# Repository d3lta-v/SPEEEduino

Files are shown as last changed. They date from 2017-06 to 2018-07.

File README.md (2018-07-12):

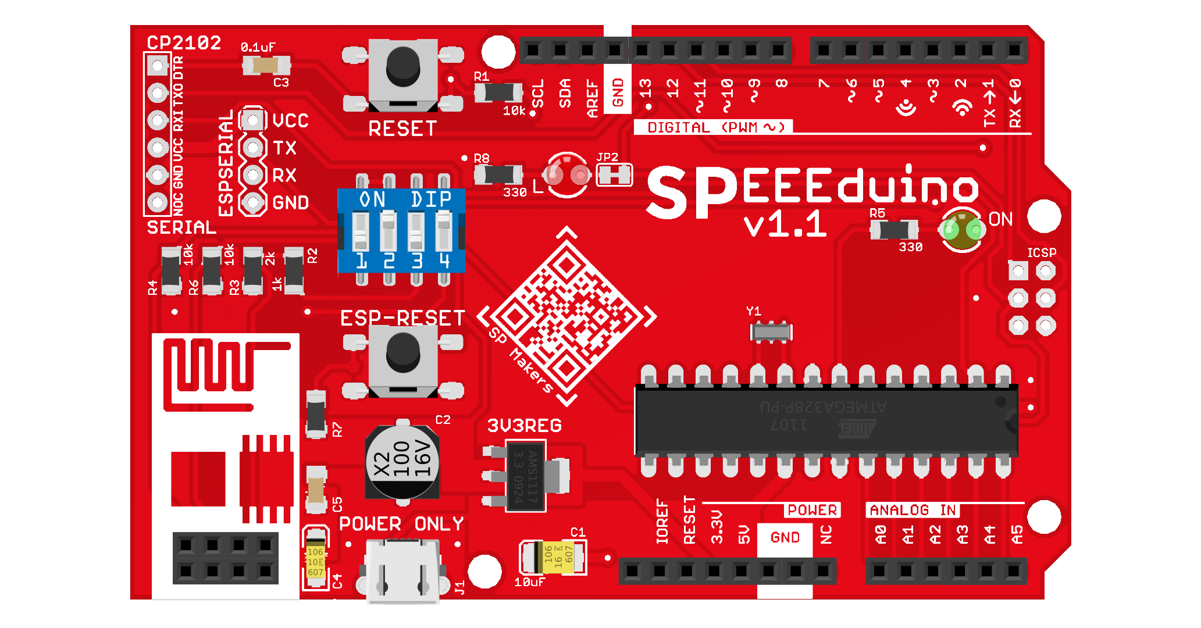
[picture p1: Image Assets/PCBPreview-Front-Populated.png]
Populated PCB


Designed by MakerFoundry LLP | Designed, assembled and tested in Singapore

# SPEEEduino
SPEEEduino is an easy to use Wi-Fi enabled microcontroller, designed and fabricated by EEE students. Users can write programs to connect or control things over the Internet.

Official Reference Website: [https://sites.google.com/view/speeeduino/home](https://sites.google.com/view/speeeduino/home)

Related project: [ESPblaster](https://github.com/sammy0025/ESPblaster)

## Technical information

### Repository Layout
* **SPEEEduino_v1.0**: EAGLE files for the old SPEEEduino v1.0, which is deprecated
* **SPEEEduino_v1.1**: EAGLE files for thew new SPEEEduino
* **Low Level Library**: The SPEEEduino Low Level Library, which is an Arduino library that provides an easy way to interface with the ESP8266-01 module with the SPEEEduino.
* **docs**: The [github.io homepage](https://sammy0025.github.io/SPEEEduino/) for the SPEEEduino
* **Image Assets**: Image assets for websites related to the SPEEEduino and markdown pages.

### Startup states table
A simplified version of this table is also available on the back of the SPEEEduino v1.1's board.

|  | GPIO0 (1) | GPIO2 (2) | ESP-RX connect to D4 (3) | ESP-TX connect to D2 (4) | ESP-RESET Button |
|---|:---:|:---:|:---:|:---:|:---:|
| Wi-Fi Enable | ⬆️ | ⬆️ | ⬆️ | ⬆️ | Leave open |
| Disconnect ESP-01 | ❎ | ❎ | ⬇️ | ⬇️ | Leave open |
| Reset ESP-01 | ❎ | ❎ | ❎ | ❎ | Press down |
| Flash ESP-01 | ⬇️ | ⬆️ | ⬇️ | ⬇️ | Press down, set switches, release |

## Contributing
Contributing to the SPEEEduino Git Repository requires you to have EAGLE 8.4 or newer which supports Managed Libraries.

SPEEEduino primarily uses EAGLE's Managed Libraries made by Sparkfun, but also contain our own custom footprints and SMD component footprints from Cytron.

## Our team
* Project Supervisor: [Teo Shin Jen](https://www.youracclaim.com/user/sjteo)
* Chief Designer: Pan Ziyue ([@sammy0025](https://twitter.com/sammy0025))
* Assistants/Advisers: Julian Kang ([@Julian_KBK](https://twitter.com/Julian_KBK)), Goh Qian Zhe ([@QianZheGoh](https://twitter.com/QianZheGoh))
* Videographer: [@QianZheGoh](https://twitter.com/QianZheGoh)
* The awesome folks at Arduino, Sparkfun and Adafruit for technical reference and ECAD models.

OSHW

Open Source Hardware (OSHW)

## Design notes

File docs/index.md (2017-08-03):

---
---

## SPEEEduino Official Webpage

Populated PCB

The SPEEEduino (SP-EEE-duino, pronounced speed-duino) is an Open Source, modified Arduino board with an integrated ESP8266-01 Wi-Fi module socket, allowing for users to connect both devices with ease. The ESP8266 enables the Arduino to connect to the Internet with Wi-Fi, making this a great starting platform for simple IoT devices and projects.

Created by the Singapore Polytechnic Makers' Club.

Students involved are Ziyue ([@sammy0025](https://twitter.com/sammy0025)), Julian Kang ([@Julian_KBK](https://twitter.com/Julian_KBK)), Qian Zhe ([@QianZheGoh](https://twitter.com/QianZheGoh)) and Sean Tin under the supervision of Mr Teo Shin Jen.

**NOTE: This home page is still incomplete, check back soon for more**

### Documentation

For documentation on this project, please refer to our [Github Wiki](https://github.com/sammy0025/SPEEEduino/wiki) for more information.

For old project logs (which are being migrated away from Google Sites to Github Pages), click [here](https://sites.google.com/view/speeeduino/home).

For source code regarding this project, simply visit our [Github](https://github.com/sammy0025/SPEEEduino)

### Our team
Chief Designer: Pan Ziyue ([@sammy0025](https://twitter.com/sammy0025))

Assistants/Advisers: Julian Kang ([@Julian_KBK](https://twitter.com/Julian_KBK)), Goh Qian Zhe ([@QianZheGoh](https://twitter.com/QianZheGoh)), Sean Tin

Videographer: [@QianZheGoh](https://twitter.com/QianZheGoh)

OSHW

Open Source Hardware (OSHW)

### Support or Contact

Having trouble with SPEEEduino and its usage? Check out our [Github Wiki](https://github.com/sammy0025/SPEEEduino/wiki).

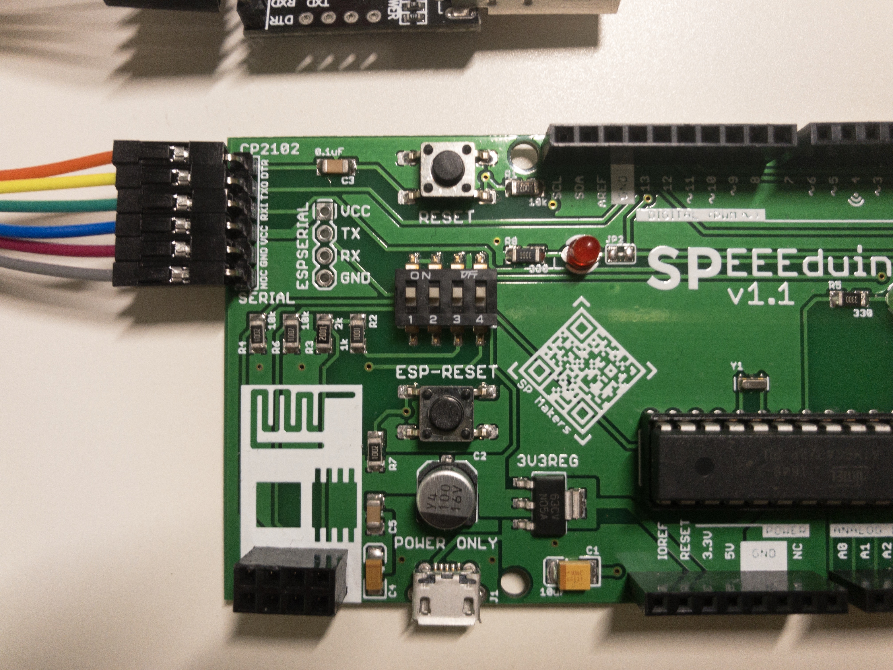
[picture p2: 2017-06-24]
Image Assets/Documentation/DIP_Switch_1.jpg

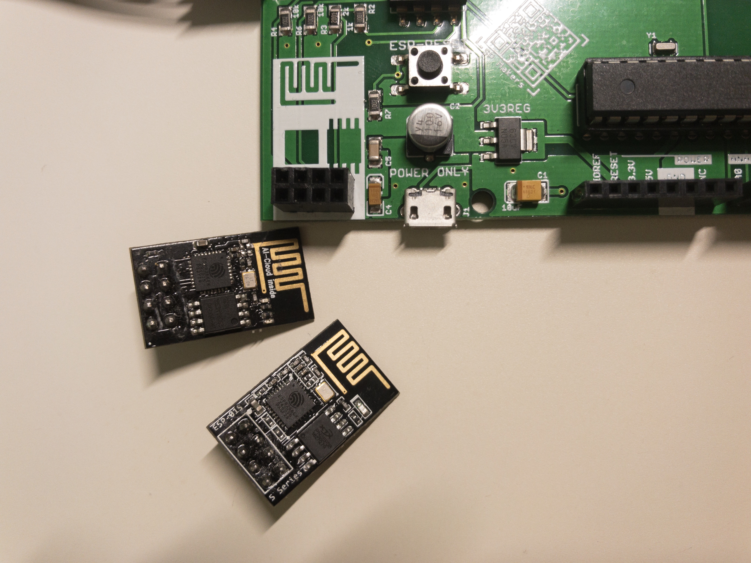
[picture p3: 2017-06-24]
Image Assets/Documentation/ESP01_Modules.jpg

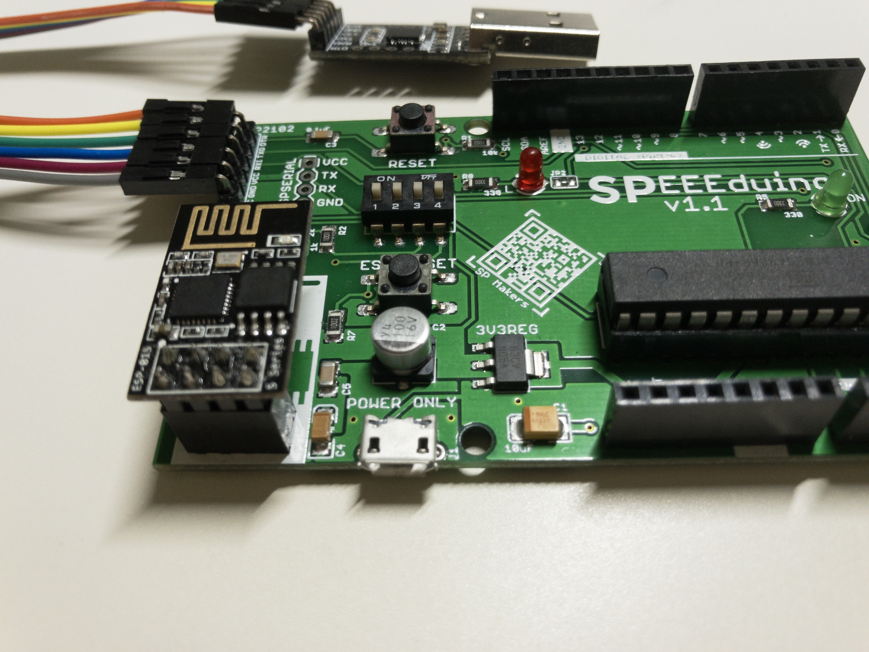
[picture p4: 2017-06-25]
Image Assets/Documentation/ESP01_Onboard.jpg

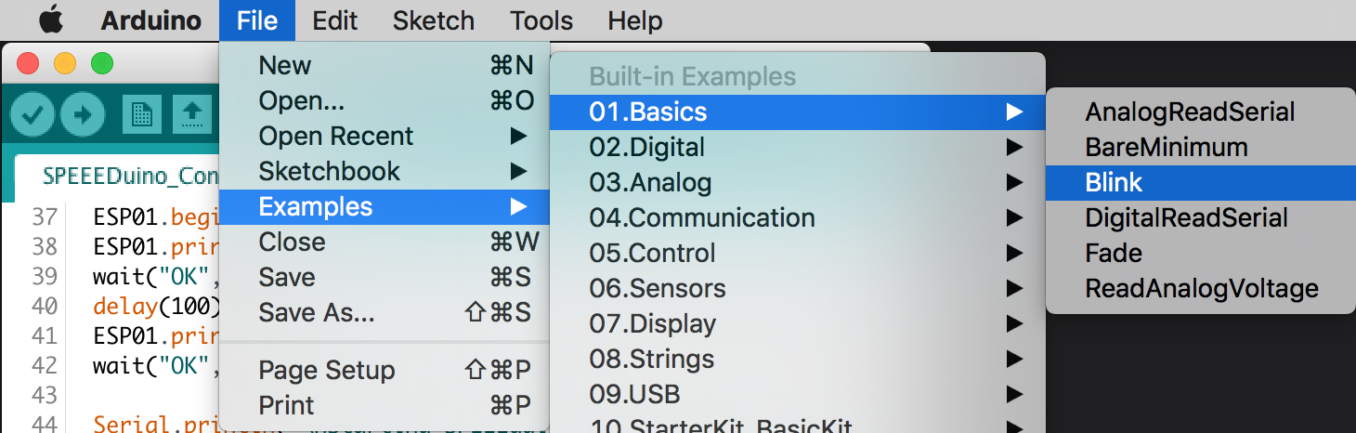
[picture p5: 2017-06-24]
Image Assets/Documentation/Blink_Select.png

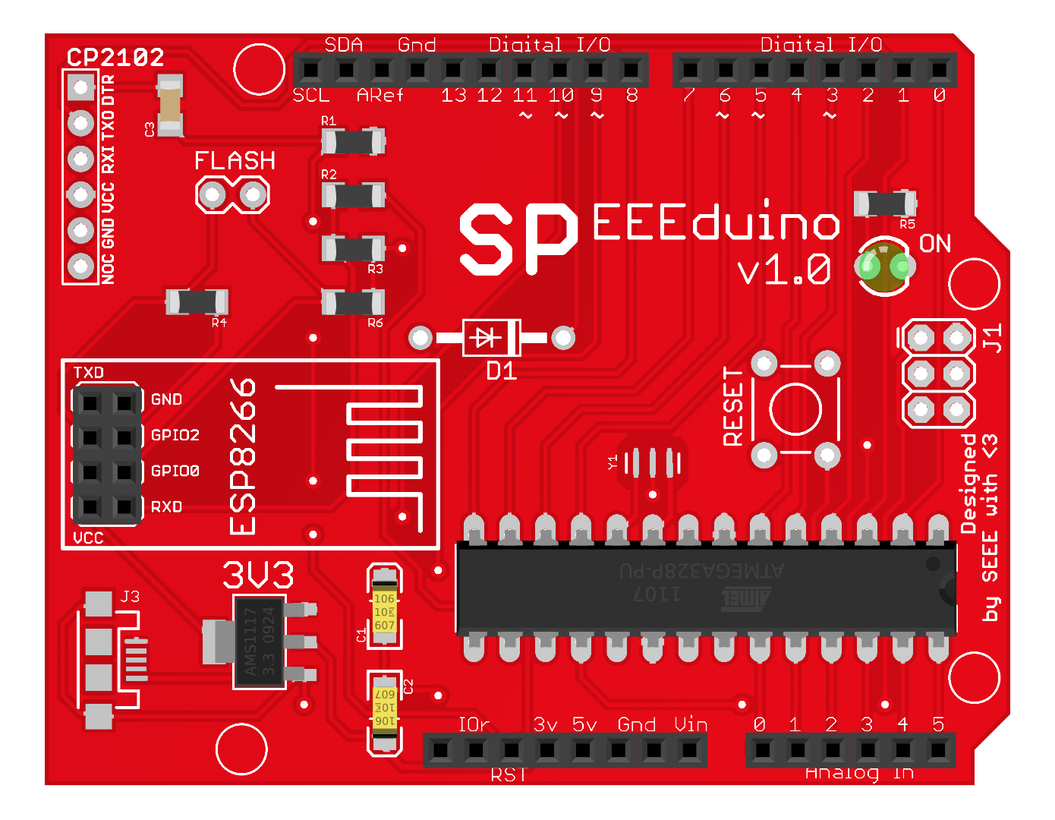
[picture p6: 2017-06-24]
Image Assets/PCBPreview-1.0-Populated.png

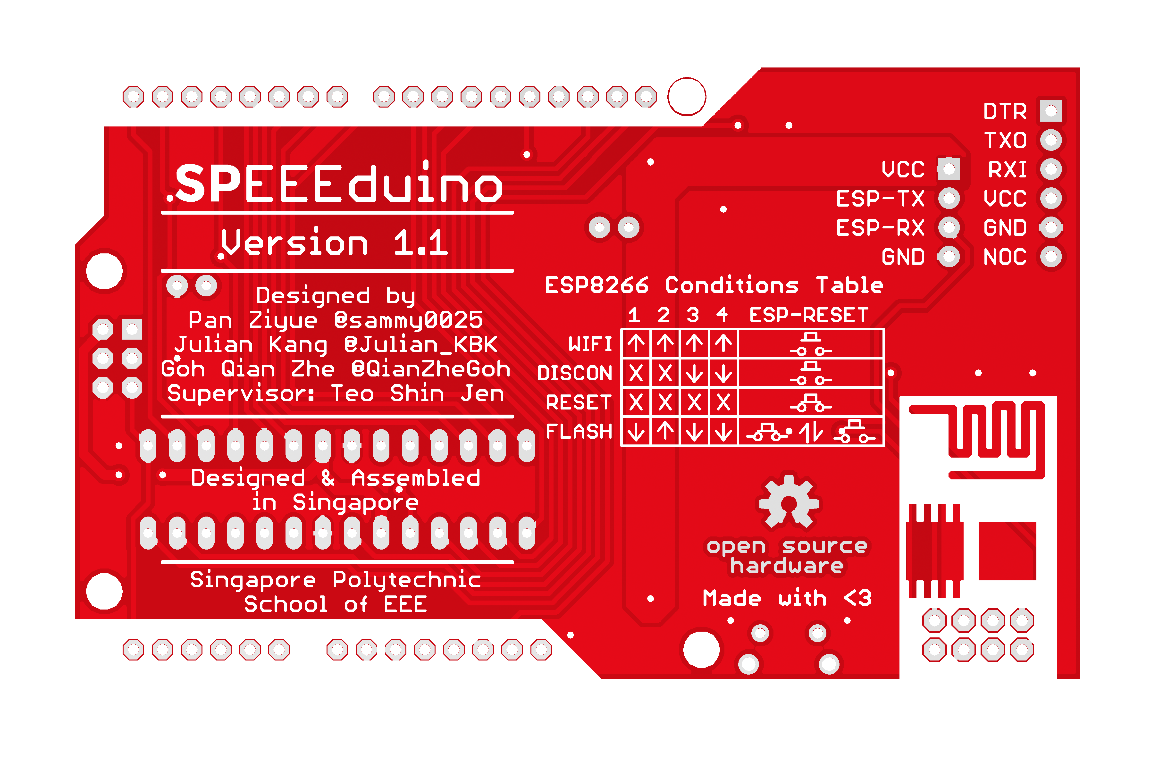
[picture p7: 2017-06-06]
Image Assets/PCBPreview-Back.png

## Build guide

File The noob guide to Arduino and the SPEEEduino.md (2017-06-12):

# The noob guide to Arduino and the SPEEEduino
This is a brief introduction to microcontrollers, focusing on the Arduino, the ESP8266 and subsequently the SPEEEduino (which is an augmentation on a conventional Arduino). This guide is meant for people with basic EEE and computing knowledge. 

The Arduino is a _microcontroller development board_. It is **NOT** a microcontroller by itself. 

A development board is distinctly different from a finished product. A finished product only has the necessary components for the user to interface with it, like a keyboard, screen or touchscreen. In this case, the user is most likely an end-user or consumer. A development board on the other hand, has all of the possible interfaces exposed to the user, who is most likely a developer. The developer can add or remove peripherals at will on a development board, unlike a consumer product which is most likely pre-assembled and unmodifiable.

A microcontroller is a self contained computer on a single chip (different from a microprocessor! A microprocessor is just the CPU). A computer usually has the following parts:

* CPU (aka microprocessor)
* RAM
* ROM (program memory, usually flash storage)
* Permanent storage (usually EEPROM)
* Interface controller (that talks with the outside world)

A microcontroller is a single chip that contains all of the above in a single package. There are many families of microcontrollers. Some notable 8-bit microcontroller families I've encountered are:
* Atmel AVR (which is what we are focusing on today)
* Microchip PIC
* PICAXE (extension on the PIC)
* STC (a Chinese clone of the venerable Intel 8051)

The only differences between different families of microcontrollers is primarily the tools used to program them, and the instruction sets used, and of course the interface (pins) available (more on that in a bit). 

## Introduction to the ATmega328P
The ATmega328P is an 8-bit microcontroller. Some of the specifications include:
 
* Bit width: 8 (in contrast to the computer or phone you are browsing this article on, which is most likely 32 or 64 bit)
* Instruction set: RISC (reduced instruction set computing) (if you are browsing this article on a phone, chances are you are using a RISC processor. If you’re on a laptop or desktop, it’s probably a CISC processor)
* Architecture: Atmel AVR (Advanced Virtual RISC, although AVR doesn't stand for anything. Architectures like x86 are used in your laptops and desktops, but ARM is probably found in phones)

The ATmega328P is just one of the many chips in Atmel’s AVR family. The `328` stands for 32 kilobytes of flash storage. The “P” at the end of the name signifies that it is the “picoPower” edition, which means it uses less power than your standard ATmega328. Here are some other chips in Atmel’s AVR family:

* ATmega168: 16 kilobyte flash
* ATmega48: 4 kilobyte flash

However, the Arduino exclusively uses the ATmega328P (which is different from the ATmega328 due to the difference in picoPower availability). Older Arduinoes like the Arduino Duemilanove may use the ATmega328 or ATmega168. 

The modern computational world has a massive cocktail of standards and, by extension, ports. Some of the common ports we see on our own computers include USB, HDMI and Thunderbolt. An ATmega328P on the other hand, has some more "exotic" ports mainly because they are no longer relevant in our current world of high speed demands, but still very much relevant in embedded systems like the Arduino due to their low speeds. 

The ATmega328P packs a variety of ports to allow maximum flexibility to the end user. Some of these ports include:

* **GPIO**: General Purpose Input/Output ports. These ports provide a variety of digital logic output and input functionality, including simple digital logic of 0s and 1s and PWM (pulse width modulation, which allows a digital circuit to emulate an analog signal). Some other GPIO ports include ADC (analog to digital) functionality, that converts an analog voltage to a digital value. All standard GPIO pins can also emulate a serial port through Software Serial, however, those emulated versions cannot reach the speed nor the reliability of a real hardware serial port. 
* **Serial**: TTL Serial ports provide easy connectivity between devices that need to send large amounts of data. A classic example of serial is actually early modems that need to send significant amounts of data compared to other even older standards like teletypewriters (it sounds exactly what it sounds like). The serial port is also used to program the Arduino. Most serial ports has the following pins (this is a non-exhaustive list):
	* **TX**: transmit
	* **RX**: receive
	* **DTR**: Data Terminal Ready
	* **CTS**: Cleared to Send	

The Arduino platform allows the user to upload programs via the chip's serial port, instead of going through an AVR programmer and an SPI port (explained below), simplifying the experience for the end user. 

* **SPI**: Serial Peripheral Interface, which is a common standard of connecting digital devices. SPI uses 3 data pins: 
	* **MOSI**: Master Out Slave In
	* **MISO**: Master In Slave Out
	* **CLK**: Master clock

The SPI interface is also used for programming the ATmega328P the official way, using a system called the ISP (in-system programmer)

* **I2C** (sometimes IIC or I²C, pronounced I-squared-C): an improvement on both serial and SPI, this platform allows daisy chaining of theoretically infinite devices together. It fixes most of the problems associated with serial and SPI by reducing the number of wires used, only using 2 data wires, SCL and SDA to communicate with theoretically infinite devices. Learn more [here](https://learn.sparkfun.com/tutorials/i2c).
	* **SDA**: Bidirectional data wire
	* **SCL**: Source clock, which is provided by the MCU

## The Arduino platform
The Arduino is nothing more than a platform (i.e. Development board), with a microcontroller and some supporting circuitry. A development board is a specialised PCB for a certain computing system or microcontroller, which provides a developer-friendly interface (such as female header pins) that makes it easier to work with than the normal commercial version. For the Arduino, there is no "commercial version" as it is purely meant to be an educational development board. I will list the supporting circuitry on a standard Arduino below:

* Frequency control: a microcontroller, much like your CPU, require a constant clock pulse. While the Atmel ATmega328P chip has its own internal oscillator, an external crystal oscillator or resonator is usually more accurate. The Arduino uses a 16MHz clock
* Power supply: the Arduino provides two sources of power, one from a DC barrel jack, which can accept roughly 7-12VDC, and through an LDO voltage regulator, provides the 5V necessary. Most of the time, the Arduino is powered via the USB port which already provides 5V. Do keep in mind that this 5V is limited to 500mA for USB 2, and 1A for USB 3. This means that you cannot attempt to power something like a high power motor off your USB port!
* Interface: the Arduino board "breaks out" the pins of the ATmega328P to allow easy access of all the pins. It also provides a reset button to force reset the microcontroller and several LEDs for debugging purposes, such as the LED on pin 13 as well as the TX and RX LEDs on the serial converter (explained below). 
* Serial converter: computers no longer communicate through a serial port these days. However, a simple 8 bit MCU like the Arduino does not have a port as advanced as USB, and therefore uses a TTL (that means, 5-0V) serial port to communicate with the outside world. As the Arduino is programmed via a USB port, there must be a device to translate USB to serial, and this is where the serial converter comes in. 

Furthermore, the Arduino platform uses this thing that most people will be confused about: the bootloader. In a normal computer, a bootloader is a small piece of software that runs every single time the computer boots up. In an Arduino, we also have a bootloader, but why? Aren't embedded systems so light they shouldn't have a bootloader?

It turns out, that programming an AVR chip the "official way" was not only expensive but also complicated for a beginner. When the Arduino was developed, it packed an interesting feature: users can upload programs using the serial port instead of using an external programmer which may be daunting. The traditional way of uploading looks a bit something like: 

`Computer > AVR ISP > AVR chip`

And the Arduino way of doing things:

`Computer > Arduino`

The major difference is that the Arduino platform has an onboard USB to serial converter, which is a lot cheaper than an AVR programmer. If you want to take a closer look, here is the full flow that's happening behind the scenes:

Traditional method: (with the device-protocol pattern. For example, computer is a device, but USB is a protocol, and so on)

`Computer > USB > Serial converter > AVR ISP > SPI > AVR chip`

Arduino method:

`Computer > USB > Serial converter > Serial > AVR chip`

This is what actually happens behind the scenes when an Arduino is being programmed (note: you will need to have a basic understanding of how serial works):

1. The computer opens the serial port. This causes the DTR pin to go low
2. As the DTR pin is directly connected to the RESET pin on the ATmega328P, this causes the the chip to reset (restart)
3. During the first few seconds of booting up, the chip is in a "programmable" state. That means that any data sent through the serial port will be taken as instructions to flash the chip with new data. If the computer does not send data in time, the chip will continue normal boot up. In this case we are assuming that the chip is being flashed
4. The chip starts to receive data and writes them to the internal flash storage
5. After receiving the data, the chip will start transmitting data back to the computer for the computer to verify the integrity of the data (in layman terms: the data written to the chip is identical to the one on the computer and has not been altered)
6. The chip reboots and begins normal execution

## ESP8266
The ESP8266 is a revolutionary new WiFi chip that is low power and cheap to operate, which is a breath of fresh air in a market where RF equipment like WiFi and Bluetooth radios always meant high markups on their prices. 

The ESP8266, believe it or not, is _also_ considered a microcontroller. It has most of the interfaces an Arduino has, such as hardware serial port and GPIOs. Later versions of the ESP8266 breaks out all of the GPIO pins, and the ESP8266 can even be used as an Arduino if you want to. However, it is often easier for people who used the Arduino platform previously to use the ESP8266 for its WiFi functionality only, and keep all of the logic on the Arduino. 

There are several different breakout boards available for the ESP8266, the oldest and the most common of which is the ESP01. It has 8 pins, listed below:

* Vcc/GND: self explanatory 
* GPIO0: This pin sets the bootloader state to use a particular source for booting up. Pull high to boot from flash memory (which usually what you want) and pull low to boot from serial port data
* GPIO2: Ordinary GPIO pin with internal pull-up resistor. Can leave this unconnected or pulled up
* TX/RX: explained above
* CH_PD: Chip enable. Should be pulled high if the chip should be “enabled”

The ESP8266 has several form factors (the more uncommon form factors are not listed):

1. ESP01: The simplest version of it with the least functionality. It is meant to purely be a no frills WiFi module and nothing more
2. ESP12: Solderable SMD version of an ESP8266 module. FCC and CE certified. 

Of course, the ESP8266 is not the be all and end all of WiFi chips. Its slow processor, limited interface and most importantly, it's lack of support for many modern technologies we take for granted such as WPA2-Enterprise authentication and TLS 1.2 HTTPS over its bare-bones command line interface. Its successor, the ESP32, has a dedicated cryptographic engine that performs specific cryptographic operations like AES and SHA2, and has a far more powerful processor capable of driving small displays. The ESP8266 is great for hacking together a simple proof of concept IoT device, but is woefully inadequate for professional deployment. 

Furthermore, there are different types of development boards built for the ESP8266 as well. For example, the [NodeMCU](https://en.wikipedia.org/wiki/NodeMCU) is a very popular development board. Another popular development board is the [WeMos D1](https://www.wemos.cc/product/d1.html), a board that has a similar form factor to an Arduino but is completely based around the ESP8266 as its main microcontroller.

## Interfacing with the ESP8266
The ESP8266 uses a system know as AT commands for issuing commands to it. This system is very commonly used by all sorts of radios with a terminal-like interface, such as GSM (mobile phone), GPS and Bluetooth radios. 

Sending a single command `AT`  through the serial port to the ESP8266 is a common smoke test to checking if the module even works at all. If it responds with `OK`, it is all good. 

Keep in mind, the ESP8266 has different baud rates for issuing AT commands, so take good note on what baud rate are you using. I have written a comprehensive guide [here on Instructables](http://www.instructables.com/id/Definitive-Guide-to-Setting-Up-Your-New-ESP01-Modu/). Usually the default baud rate is 115200. 

In addition to the AT command line, the ESP8266 can run other operating systems and development environments. Some people out there have even ported the Arduino IDE to be compatible with an ESP8266, so certain pieces of Arduino code can be run on an ESP8266 with the ESP8266 itself acting as the microcontroller, without much modification. Espressif themselves provides two "official" versions, the original AT commands version, and another version with an RTOS (real time operating system). 

## Putting it all together 
Now, we are going to put the Arduino and the ESP8266 together to form a powerful and cheap (relatively, compared with older WiFi/"smart" solutions) combination. The Arduino handles all of the logic, given the power (once again, relatively) of the AVR architecture and the familiarity to people + more compatibility and support with Arduino. The ESP8266 handles only and only the WiFi part. 

The plan is simple. Connect the ESP8266 with an Arduino, with its serial port going to a software emulated serial port on the Arduino (to prevent taking up the hardware serial port, which is used when programming the Arduino). 

_But wait there's more!_

The problem is we can't just plug an ESP8266 directly into an Arduino via the serial pins. The Arduino's Software Serial capabilities are actually very limited. There is no way it can communicate at anything higher than 52700 baud. That means we have to manually reduce the baud rate of the ESP8266 to a more tolerable level, such as 9600.

The following command will lower the baud rate to 9600, with 1 stop bit, no parity bits and no control flow:

`AT+UART_DEF=9600,1,0,0`

## The SPEEEduino
The SPEEEduino is meant to be a fusion of the two devices, providing easy access to both devices' functionality without complicated wiring and level shifting (which is converting between different voltage levels for communication to and from devices with different voltages). The ESP8266 is flashed with Espressif's original AT firmware, and connected to the SPEEEduino via a 2x4 female header. 

By fusing these two devices together, we can get the best of both worlds: full compatibility with existing Arduino code and hardware as it is running on an AVR chip that most makers know and love, and the cheap WiFi capabilities of the ESP8266. 

The SPEEEduino is destined to have 2 major versions: 
Version 1 will focus on basic functionality, that fuses an Arduino with an ESP8266 ESP01 breakout board. 
Version 2 will focus on extended functionality by creating a Arduino-ESP32 hybrid. The ESP32 is the successor of the ESP8266, and packs far more functionality. 

_But wait, why would anyone want a SPEEEduino if we already have a WeMos D1?_

Good question. As it turns out, while you can program the WeMos D1 with Arduino code (and by extension, every single ESP8266 module and development board out there), there is a massive codebase that is based around the Arduino’s ATmega328P chip. Many libraries that rely on highly time-sensitive operations are optimised only for the ATmega328P chip. The reason why we made the SPEEEduino is to maintain backwards compatibility with the Arduino community’s massive amounts of source code, while giving the standard Arduino a cheap way to add IoT to it.

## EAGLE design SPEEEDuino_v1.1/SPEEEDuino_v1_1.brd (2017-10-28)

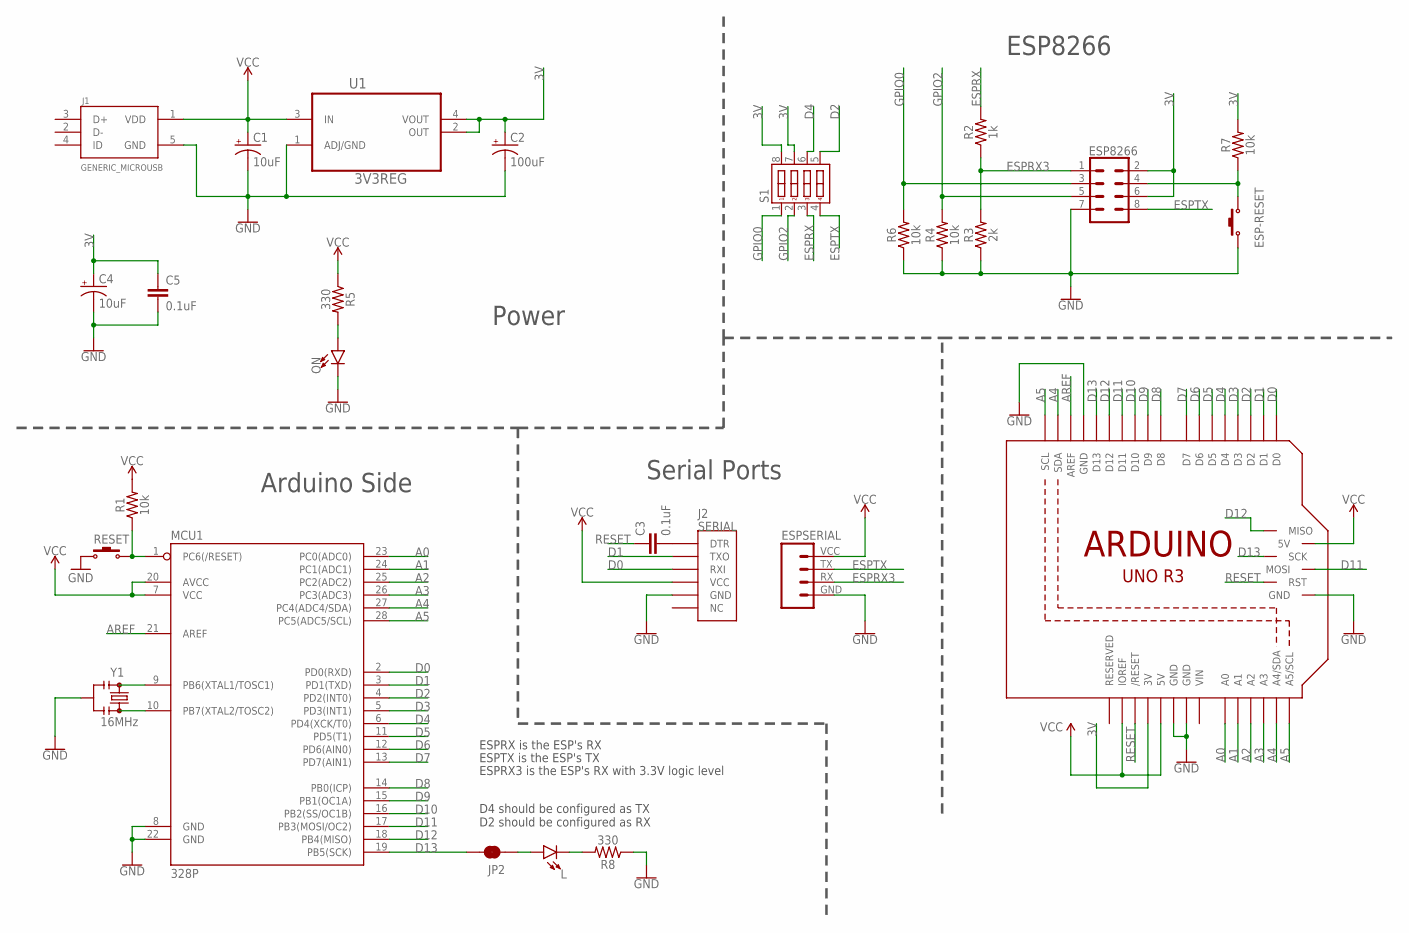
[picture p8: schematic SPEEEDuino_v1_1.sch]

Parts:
C1: 10uF; EIA3528
C2: 100uF; PANASONIC_D
C3, C5: 0.1uF; 1206
C4: 10uF; EIA3216
ESP8266: CONN_04X2; 2X4
ESP-RESET: SW-PB_(KAN0641); S-SP-4N-KAN0641
ESPSERIAL: ESP8266-SERIAL0; 1X04
J1: GENERIC_MICROUSB; FRAMATOME_10118194-0001LF
J2: SERIAL; CP2102_DEVICE_SIDE
JP2: JUMPER-SMT_2_NC_TRACE_SILK; SMT-JUMPER_2_NC_TRACE_SILK
L: LED3MM; LED_3MM
M1: ARDUINO_R3_ICSP; ARDUINOR3_ICSP
MCU1: 328P; DIP28
ON: LED3MM; LED_3MM
R1, R4, R6, R7: 10k; 1206
R2: 1k; 1206
R3: 2k; 1206
R5, R8: 330; 1206
RESET: SW-PB_(KAN0641); S-SP-4N-KAN0641
S1: 4 WAYS; SW-DIP-4-SMD
U1: 3V3REG; SOT230P696X180-4N
Y1: 16MHz; RESONATOR-SMD-3.2X1.3

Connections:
3V: C2.+, C4.+, C5.1, ESP8266.2, ESP8266.6, M1.3V, R7.2, S1.7, S1.8, U1.2 (OUT), U1.4 (VOUT)
A0: M1.A0, MCU1.23 (PC0(ADC0))
A1: M1.A1, MCU1.24 (PC1(ADC1))
A2: M1.A2, MCU1.25 (PC2(ADC2))
A3: M1.A3, MCU1.26 (PC3(ADC3))
A4: M1.A4 (A4/SDA), M1.SDA, MCU1.27 (PC4(ADC4/SDA))
A5: M1.A5 (A5/SCL), M1.SCL, MCU1.28 (PC5(ADC5/SCL))
AREF: M1.AREF, MCU1.21 (AREF)
D0: J2.P$3 (RXI), M1.D0, MCU1.2 (PD0(RXD))
D1: J2.P$2 (TXO), M1.D1, MCU1.3 (PD1(TXD))
D2: M1.D2, MCU1.4 (PD2(INT0)), S1.5
D3: M1.D3, MCU1.5 (PD3(INT1))
D4: M1.D4, MCU1.6 (PD4(XCK/T0)), S1.6
D5: M1.D5, MCU1.11 (PD5(T1))
D6: M1.D6, MCU1.12 (PD6(AIN0))
D7: M1.D7, MCU1.13 (PD7(AIN1))
D8: M1.D8, MCU1.14 (PB0(ICP))
D9: M1.D9, MCU1.15 (PB1(OC1A))
D10: M1.D10, MCU1.16 (PB2(SS/OC1B))
D11: M1.D11, M1.MOSI, MCU1.17 (PB3(MOSI/OC2))
D12: M1.D12, M1.MISO, MCU1.18 (PB4(MISO))
D13: JP2.2, M1.D13, M1.SCK, MCU1.19 (PB5(SCK))
DTR: C3.2, J2.P$1 (DTR)
ESPRESET: ESP8266.4, ESP-RESET.3 (2), ESP-RESET.4 (2), R7.1
ESPRX: R2.2, S1.3
ESPRX3: ESP8266.1, ESPSERIAL.RX (TX), R2.1, R3.2
ESPTX: ESP8266.8, ESPSERIAL.TX (RX), S1.4
GND: C1.C (-), C2.-, C4.-, C5.2, ESP8266.7, ESP-RESET.1, ESP-RESET.2 (1), ESPSERIAL.GND (VCC), J1.5 (GND), J2.P$5 (GND), M1.GND, M1.GND@1 (GND), M1.GND@2 (GND), M1.GND@3 (GND), MCU1.8 (GND), MCU1.22 (GND), ON.K (C), R3.1, R4.1, R6.1, R8.1, RESET.1, RESET.2 (1), U1.1 (ADJ/GND), Y1.2
GPIO0: ESP8266.3, R6.2, S1.1
GPIO2: ESP8266.5, R4.2, S1.2
unnamed: MCU1.10 (PB7(XTAL2/TOSC2)), Y1.3
unnamed: L.K (C), R8.2
unnamed: JP2.1, L.A
unnamed: ON.A, R5.2
unnamed: MCU1.9 (PB6(XTAL1/TOSC1)), Y1.1
RESET: C3.1, M1.RESET (/RESET), M1.RESET_ICSP (RST), MCU1.1 (PC6(/RESET)), R1.1, RESET.3 (2), RESET.4 (2)
VCC: C1.A (+), ESPSERIAL.VCC (GND), J1.1 (VDD), J2.P$4 (VCC), M1.5V, M1.5V_ICSP (5V), M1.IOREF, MCU1.7 (VCC), MCU1.20 (AVCC), R1.2, R5.1, U1.3 (IN)
VIN: M1.VIN

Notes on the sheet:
ESPRX is the ESP's RX
ESPTX is the ESP's TX
D4 should be configured as TX D2 should be configured as RX
ESPRX3 is the ESP's RX with 3.3V logic level
Power
Arduino Side
Serial Ports
ESP8266

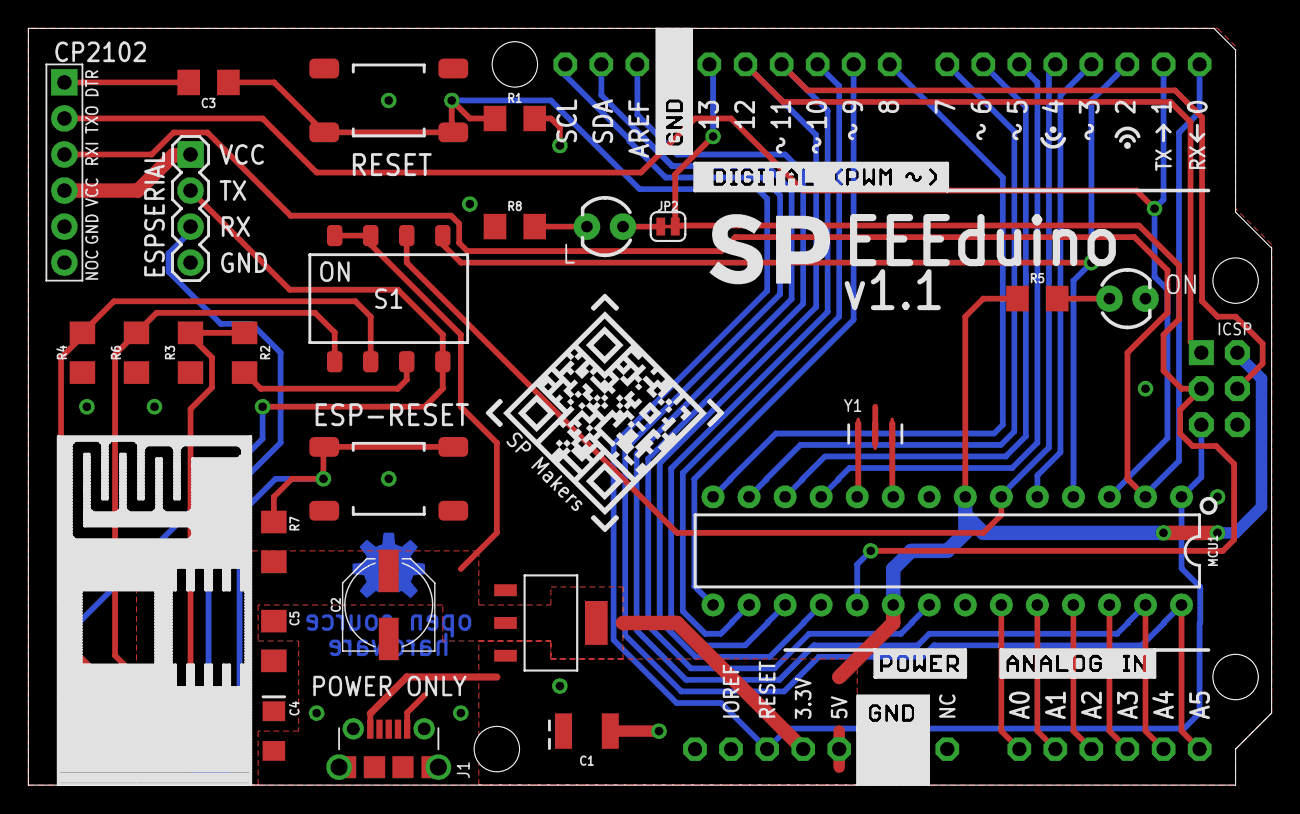
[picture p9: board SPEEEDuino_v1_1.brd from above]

Board: 2 copper layers, 87.6 x 53.3 mm, 33 parts (0 on the bottom side), 37 nets.

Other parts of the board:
U$1: ESP8266-NEGASILK
U$2: SP-LOGO-BIGGER
U$3: ESP8266-NEGASILK-INV
U$4: OSHW-LOGO-M_COPPER-SOLDERMASK-INV
U$5: MAKERCLUB-QR
U$6: SP-LOGO-SMALL-INV

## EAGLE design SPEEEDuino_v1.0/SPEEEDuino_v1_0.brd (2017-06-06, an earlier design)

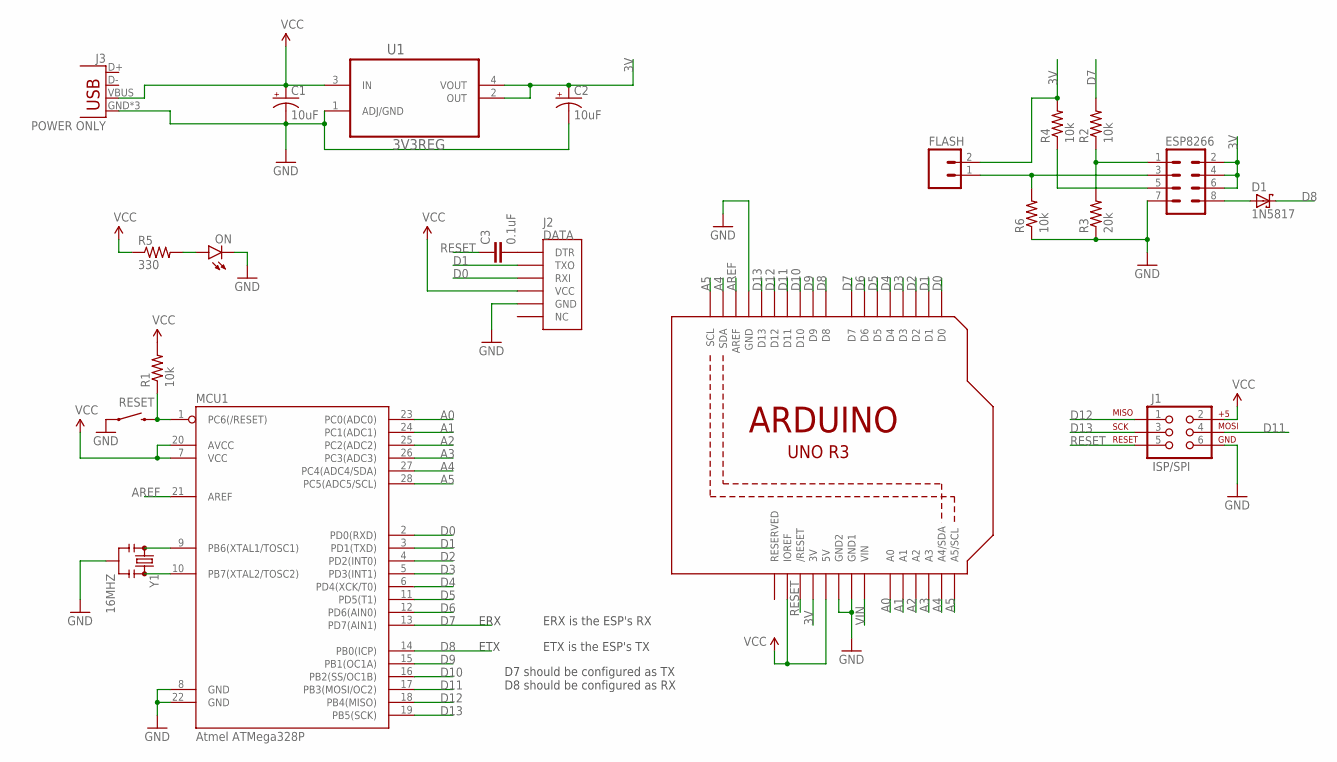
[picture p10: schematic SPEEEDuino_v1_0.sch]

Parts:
C1, C2: 10uF; EIA3216-KIT
C3: 0.1uF; 1206
D1: 1N5817; DO41-10
ESP8266: M04X2; 2X4
FLASH: M02LOCK; 1X02_LOCK
J1: ISP/SPI; 2X3
J2: DATA; CP2102_DEVICE_SIDE
J3: POWER ONLY; USB-MICROB
MCU1: Atmel ATMega328P; DIL28-3
ON: LED3MM
R1, R2, R4, R6: 10k; 1206
R3: 20k; 1206
R5: 330; 1206
RESET: SWITCH-MOMENTARY-2PTH; TACTILE-PTH
U1: 3V3REG; SOT230P696X180-4N
U2: ARDUINOR3-DIMENSION; ARDUINOR3
Y1: 16MHZ; RESONATOR-SMD

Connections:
3V: C2.A (+), ESP8266.2, ESP8266.4, ESP8266.6, FLASH.2, R4.2, U1.2 (OUT), U1.4 (VOUT), U2.3V
A0: MCU1.23 (PC0(ADC0)), U2.A0
A1: MCU1.24 (PC1(ADC1)), U2.A1
A2: MCU1.25 (PC2(ADC2)), U2.A2
A3: MCU1.26 (PC3(ADC3)), U2.A3
A4: MCU1.27 (PC4(ADC4/SDA)), U2.A4 (A4/SDA), U2.SDA
A5: MCU1.28 (PC5(ADC5/SCL)), U2.A5 (A5/SCL), U2.SCL
AREF: MCU1.21 (AREF), U2.AREF
D0: J2.P$3 (RXI), MCU1.2 (PD0(RXD)), U2.D0
D1: J2.P$2 (TXO), MCU1.3 (PD1(TXD)), U2.D1
D2: MCU1.4 (PD2(INT0)), U2.D2
D3: MCU1.5 (PD3(INT1)), U2.D3
D4: MCU1.6 (PD4(XCK/T0)), U2.D4
D5: MCU1.11 (PD5(T1)), U2.D5
D6: MCU1.12 (PD6(AIN0)), U2.D6
D7: MCU1.13 (PD7(AIN1)), R2.2, U2.D7
D8: D1.C, MCU1.14 (PB0(ICP)), U2.D8
D9: MCU1.15 (PB1(OC1A)), U2.D9
D10: MCU1.16 (PB2(SS/OC1B)), U2.D10
D11: J1.4, MCU1.17 (PB3(MOSI/OC2)), U2.D11
D12: J1.1, MCU1.18 (PB4(MISO)), U2.D12
D13: J1.3, MCU1.19 (PB5(SCK)), U2.D13
GND: C1.C (-), C2.C (-), ESP8266.7, J1.6, J2.P$5 (GND), J3.GND, J3.MT1 (GND), J3.MT2 (GND), MCU1.8 (GND), MCU1.22 (GND), ON.K (C), R3.1, R6.1, RESET.1, U1.1 (ADJ/GND), U2.GND, U2.GND1, U2.GND2, Y1.2
unnamed: MCU1.10 (PB7(XTAL2/TOSC2)), Y1.3
unnamed: ESP8266.1, R2.1, R3.2
unnamed: ESP8266.5, R4.1
unnamed: ON.A, R5.2
unnamed: MCU1.9 (PB6(XTAL1/TOSC1)), Y1.1
unnamed: C3.2, J2.P$1 (DTR)
unnamed: D1.A, ESP8266.8
unnamed: ESP8266.3, FLASH.1, R6.2
RESET: C3.1, J1.5, MCU1.1 (PC6(/RESET)), R1.1, RESET.3 (2), U2.RESET (/RESET)
VCC: C1.A (+), J1.2, J2.P$4 (VCC), J3.VBUS, MCU1.7 (VCC), MCU1.20 (AVCC), R1.2, R5.1, U1.3 (IN), U2.5V, U2.IOREF
VIN: U2.VIN

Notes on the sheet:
ERX
ETX
ERX is the ESP's RX
ETX is the ESP's TX
D7 should be configured as TX D8 should be configured as RX

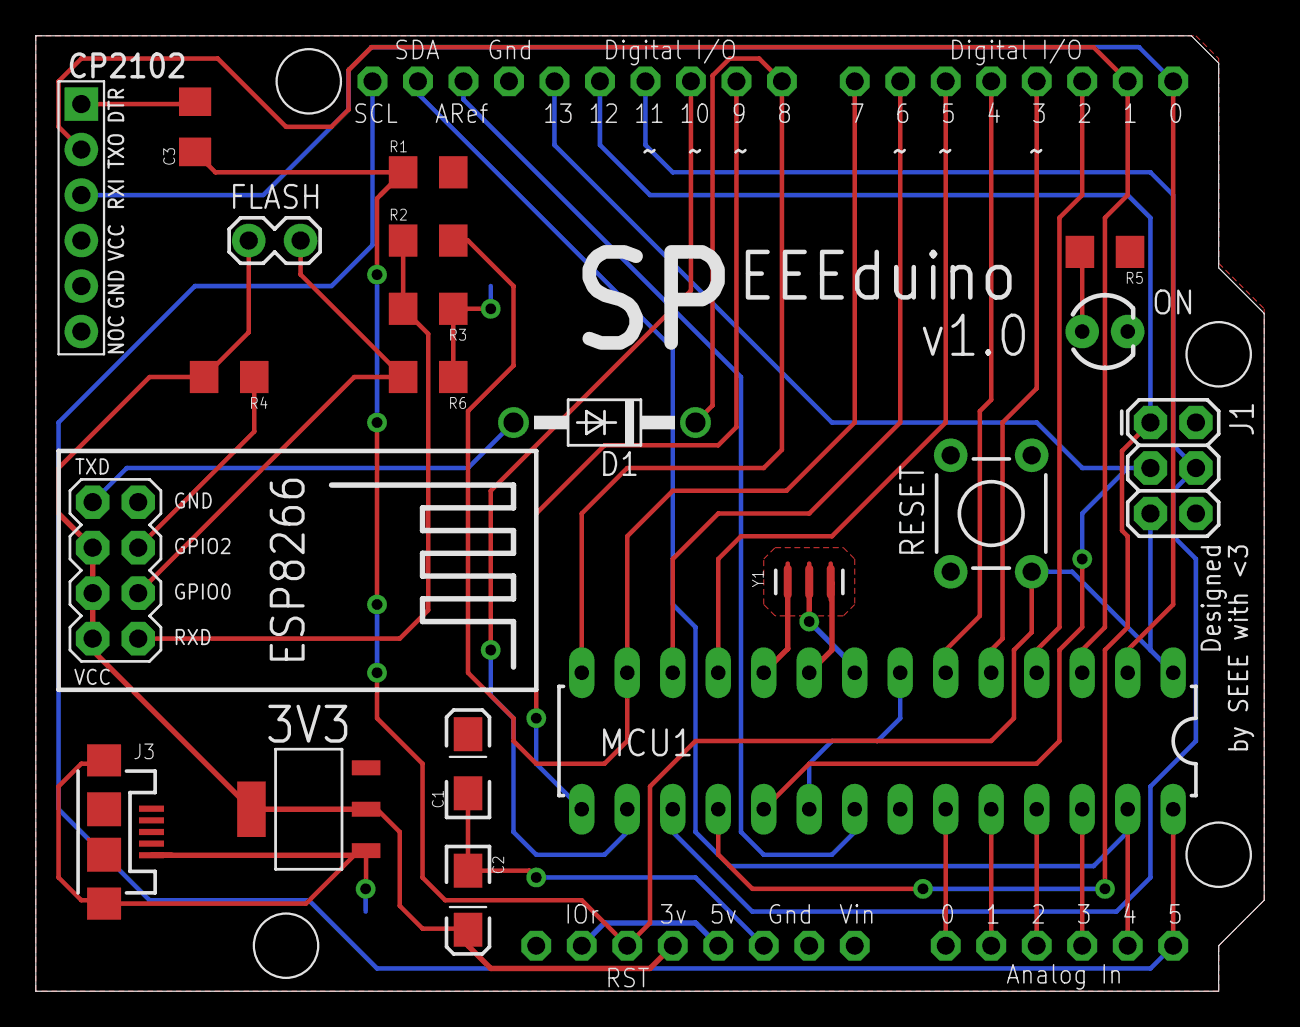
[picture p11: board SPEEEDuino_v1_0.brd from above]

Board: 2 copper layers, 68.6 x 53.3 mm, 21 parts (0 on the bottom side), 33 nets.

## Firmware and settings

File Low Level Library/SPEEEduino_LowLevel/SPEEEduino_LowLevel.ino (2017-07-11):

//
// SPEEEduino_LowLevel
//
// A low level ESP8266 code library for the SPEEEduino v1.1
// Developed with [embedXcode](http://embedXcode.weebly.com)
//
// Author 		Pan Ziyue
// 				MakerFoundry
//
// Date			8/7/17 9:42 PM
// Version		<#version#>
//
// Copyright	© Pan Ziyue, 2017
// Licence		<#licence#>
//
// See         ReadMe.txt for references
//


// Core library for code-sense - IDE-based
#if defined(ENERGIA) // LaunchPad specific
#include "Energia.h"
#elif defined(TEENSYDUINO) // Teensy specific
#include "Arduino.h"
#elif defined(ESP8266) // ESP8266 specific
#include "Arduino.h"
#elif defined(ARDUINO) // Arduino 1.8 specific
#include "Arduino.h"
#else // error
#error Platform not defined
#endif // end IDE

// Set parameters


// Include application, user and local libraries
#include "SPEEEduino_LowLevel_Library.h"


// Define structures and classes


// Define variables and constants


// Prototypes


// Utilities


// Functions


// Add setup code
void setup()
{
    ;
}

// Add loop code
void loop()
{
    ;
}

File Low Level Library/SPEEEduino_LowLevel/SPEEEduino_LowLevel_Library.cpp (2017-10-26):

//
// SPEEEduino_LowLevel_Library.cpp
// Library C++ code
// ----------------------------------
// Developed with embedXcode
// http://embedXcode.weebly.com
//
// Project 		SPEEEduino_LowLevel Library
//
// Created by 	Pan Ziyue, 8/7/17 9:42 PM
// 				MakerFoundry
//
// Copyright 	© Pan Ziyue, 2017
// Licence 		<#licence#>
//
// See 			SPEEEduino_LowLevel_Library.cpp.h and ReadMe.txt for references
//


#include "SPEEEduino_LowLevel_Library.h"
#include <avr/pgmspace.h>

#pragma mark Constants stored in program memory

#pragma mark Very basic commands
const char NEWLINE[] PROGMEM = "\r\n";
const char AT[] PROGMEM = "AT\r\n";

#pragma mark Basic commands
const char AT_GMR[] PROGMEM = "AT+GMR\r\n";
const char AT_RST[] PROGMEM = "AT+RST\r\n";

#pragma mark Wi-Fi commands
const char AT_CWLAP[] PROGMEM = "AT+CWLAP\r\n";
const char AT_CIFSR[] PROGMEM = "AT+CIFSR\r\n";
const char AT_CWQAP[] PROGMEM = "AT+CWQAP\r\n";
const char AT_CWDHCP_DEF[] PROGMEM = "AT+CWDHCP_DEF=1,";
const char AT_CWHOSTNAME[] PROGMEM = "AT+CWHOSTNAME=";
const char AT_CIPSTA_CUR[] PROGMEM = "AT+CIPSTA_CUR=";
const char AT_CIPSTA_DEF[] PROGMEM = "AT+CIPSTA_DEF=";

#pragma mark Connection commands
const char AT_CIPSTART[] PROGMEM = "AT+CIPSTART=\"";
const char AT_CIPSAP[] PROGMEM = "AT+CWSAP_DEF=";

#pragma mark - Constructor

SPEEEduino_LowLevel::SPEEEduino_LowLevel(bool debugMode=false) : _ESP01UART(2, 4) {
    SPEEEduino_LowLevel::debug = debugMode;
}

#pragma mark - Public functions

#pragma mark - Low level features

/*!
 * @brief Inputs raw text into the ESP-01 module. This command INCLUDES the carriage return and
 * newline characters
 * @warning Make sure that you manually check for the response with the wait() function
 * @param input Your input into the ESP8266 module
 */
void SPEEEduino_LowLevel::rawInput(String input) {
    _ESP01UART.print(input);
    writeCommandFromPROGMEM(NEWLINE);
}

#pragma mark - Serial link functions

/*!
 * @brief Opens the serial link from the SPEEEduino to the ESP-01 module
 */
void SPEEEduino_LowLevel::openLink() {
    if (SPEEEduino_LowLevel::debug) {
        Serial.begin(9600);
    }
    _ESP01UART.begin(9600);
}

/*!
 * @brief Opens the serial link from the SPEEEduino to the ESP-01 module, and imposes an artificial delay
 *
 * @param delayTime The time to wait before opening the serial port. Defaults to 5 seconds.
 */
void SPEEEduino_LowLevel::slowOpenLink(int delayTime=5000) {
    if (debug) {
        Serial.begin(9600);
    }
    delay(delayTime);
    _ESP01UART.begin(9600);
}

#pragma mark - Basic functions

/*!
 * @brief A simple smoke test to see if the module responds
 *
 * @return 0, if the test is successful and -1 if the test times out
 */
int16_t SPEEEduino_LowLevel::smokeTest() {
    writeCommandFromPROGMEM(AT);
    return wait("OK", 2000);
}

/*!
 * @brief Lists the firmware version of the firmware on board.
 * This information contains the AT version, SDK version and compile time
 *
 * @return 0, if it responds and -1 if it times out
 */
int16_t SPEEEduino_LowLevel::listVersion() {
    writeCommandFromPROGMEM(AT_GMR);
    return wait("OK", 5000);
}

/*!
 * Software resets the module
 *
 * @return 0, if it successfully resets and -1 if it times out
 */
int16_t SPEEEduino_LowLevel::reset() {
    writeCommandFromPROGMEM(AT_RST);
    return wait("OK", 5000);
}

/*!
 * @brief Initiates the deep sleep feature for the ESP8266 module
 *
 * @warning This is a blocking function with potentially long delays if the blocking flag is set to true
 * @param sleepTime Time to sleep, in milliseconds. This must not exceed the length of an unsigned 16-bit integer
 * @param blocking Whether or not to block the SPEEEduino's MCU using the wait() function
 * @return 0, if it successfully sleeps and recovers and -1 if it times out (when blocking=true), and always 0 if blocking = false
 */
int16_t SPEEEduino_LowLevel::beginDeepSleep(uint16_t sleepTime, bool blocking) {
    String command = "AT+GSLP=";
    command += sleepTime;
    _ESP01UART.print(command);
    writeCommandFromPROGMEM(NEWLINE);
    if (blocking) {
        return wait("OK", sleepTime + 100);
    }
    return 0;
}

#pragma mark - Wi-Fi connectivity functions

/*!
 * @brief Sets the Wi-Fi mode of the device to operate as a Wi-Fi station (client), access point, or both.
 * This setting will be saved in non-volatile memory
 *
 * @param mode The mode of the device to set. Accepts STATION, AP and BOTH
 * @return 0 if successfully set Wi-Fi mode, -1 if it timed out
 */
int16_t SPEEEduino_LowLevel::setWiFiMode(WiFiMode mode) {
    _ESP01UART.print("AT+CWMODE_DEF=");
    _ESP01UART.print(uint8_t(mode));
    writeCommandFromPROGMEM(NEWLINE);
    return wait("OK", 5000);
}

/*!
 * @brief Lists the access points around the device
 *
 * @return 0 if successfully listed all the access points, -1 if the request timed out
 */
int16_t SPEEEduino_LowLevel::listAP() {
    writeCommandFromPROGMEM(AT_CWLAP);
    return wait("OK", 10000);
}

/*!
 * @brief Joins an access point with the SSID and password specified. Only works for PSK-based networks (password only)
 *
 * @param ssid The SSID of the access point
 * @param password The password of the access point
 * @return 0 if successfully joined access point, 1 if it failed, and -1 if it timed out
 */
int16_t SPEEEduino_LowLevel::joinAP(String ssid, String password) {
    _ESP01UART.print("AT+CWJAP_DEF=\"");
    _ESP01UART.print(ssid);
    _ESP01UART.print("\",\"");
    _ESP01UART.print(password);
    _ESP01UART.print("\"\r\n");
    return wait("OK;FAIL",30000);
}

/*!
 * @brief Disconnect from an access point.
 *
 * @return 0 if successfully disconnected access point, 1 if it failed, and -1 if it timed out
 */
int16_t SPEEEduino_LowLevel::disconnectAP() {
    writeCommandFromPROGMEM(AT_CWQAP);
    return wait("OK;FAIL",5000);
}

/*!
 * @brief Get the IP address of the module. If the module is in station mode, it retrieves the assigned IP address of the module.
 * If the module is in SoftAP mode, it will retrieve the IP address of the access point created by the module.
 *
 * @return 0, if it successfully returns the IP address and -1 if it times out
 */
int16_t SPEEEduino_LowLevel::getLocalIP() {
    writeCommandFromPROGMEM(AT_CIFSR);
    return wait("OK",5000);
}

/*!
 * @brief Sets the DHCP to be enabled or disabled for both station and softAP modes. This
 *
 * @warning This function is only for station mode only!
 * @param enabled Whether or not to enable the DHCP server/client
 * @return 0 if successfully set DHCP mode, -1 if it timed out
 */
int16_t SPEEEduino_LowLevel::setDHCPEnabled(bool enabled) {
    writeCommandFromPROGMEM(AT_CWDHCP_DEF);
    char one = '1';
    char zero = '0';
    _ESP01UART.print(enabled ? one : zero);
    writeCommandFromPROGMEM(NEWLINE);
    return wait("OK", 5000);
}
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

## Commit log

2017-06-06 added populated PCB preview
2017-06-06 added populated board to README
2017-06-06 slightly modified PCB preview
2017-06-12 Added the noob guide to Arduino and SPEEEduino
2017-06-24 Changed silkscreen text sizes on 1.1, added more documentation in docs
    [SPEEEDuino_v1_0.brd, SPEEEDuino_v1_0.sch, SPEEEDuino_v1_1.brd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]
2017-06-24 Added Arduino IDE documentation pictures
2017-06-24 Added blink demonstration for Arduino IDE
2017-06-24 Cropped screenshots from Arduino IDE
2017-07-11 Slightly altered method names to Arduino's API styles guide
2017-09-13 Added fully functional multiple connection mode data sending, and optimised more code with C-equivalents
    [SPEEEDuino_v1_1.brd]
2017-09-13 Renamed low level library to allow Arduino IDE installation
2017-09-13 New Gerber files for larger silkscreen text
2017-09-14 Added IR sensor code example
2017-10-17 Added ParkLamp example
    [SPEEEDuino_v1_1.brd]
2017-10-20 Updated examples to comment out DHCP enabling to prevent weird bug
    [IR_Sensor_ThingSpeak.ino, ParkLamp.ino, Retrieve_Webpage.ino]
2017-10-21 Fixed minor bug with static IP on the low level library
    [SPEEEduino_LowLevel_Library.cpp]
2017-10-28 Updated v1.1 schematics and board to use Sparkfun's Managed libraries
    [SPEEEDuino_v1_1.brd, SPEEEDuino_v1_1.sch]

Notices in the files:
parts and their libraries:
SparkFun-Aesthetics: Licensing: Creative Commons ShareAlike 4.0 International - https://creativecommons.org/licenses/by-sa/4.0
